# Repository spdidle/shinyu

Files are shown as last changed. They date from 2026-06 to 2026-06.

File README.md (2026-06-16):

# A-Side 🎼



## What is this?

A-Side is a cassette tape inspired hub to connect full size SD cards among other things to my laptop. I own several cameras but it's not convenient at all to find my dongle and connect it. So why not use a cute form to easily see your pictures!

## Why did I make this?

I love cassette tapes and cameras. That's it!

Loving cameras mean that every time I need to view my photos, upload my photos, anything to do with my photos, it's such a hassle! Grabbing my SD card reader, then my hard drive, sometimes another dongle... Anyways, it's just way too much work. So I decided to make my own SD card dongle-esque thing, with 2 USB-A ports to facilitate any connecting of hard drives, and 2 SD card slots to maximize the photo goodness. When I don't need to fiddle with photos, it can also act as a normal USB hub, allowing me to plug in keyboard or mice into my laptop.

## Features

- **2 USB-A ports** for portable hard drives, keyboards, or mice
- **2 Full-Size SD Card slots** for photos!
- **USB-C port** because nowadays, everything seems to be USB-C...

## How does it work?

Very self explanitory! Grab your favourite USB-C to USB-C cable, plug one end into your computer, the other into the hub, and voila! You are now able to plug whatever you want into this cute little cassette tape.

## Design

Designed in KiCad, schematic and board files are in this repo:
<p align="center">
  
  
  


</p>

Case was designed (+ rendered) in Fusion360:
<p align="center">

</p>

## BOM (Bill Of Materials)
|Designator |Component Name / Description  |Package |Value / Spec |Qty|Unit Price (USD)|Total (USD)|Primary Supplier|Part Number / Source Link |
|---|---|---|---|---|---|---|---|---|
|C1, C2 |Multilayer Ceramic Capacitor  |0805 |22pF |2  |0.4600 |$0.92 |LCSC |https://www.lcsc.com/product-detail/C1804.html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 |
|C3 |Multilayer Ceramic Capacitor  |0805 |1uF |1  |0.9400 |$0.94 |LCSC |https://www.lcsc.com/product-detail/C28323.html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 |
|C10 |Multilayer Ceramic Capacitor  |0805 |4.7uF |1  |0.4300 |$0.43 |LCSC |https://www.lcsc.com/product-detail/C1779.html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 |
|C11,C12,C13,C14,C15,C16,C17,C19,C20,C4,C5,C6,C7,C8,C9|Multilayer Ceramic Capacitor  |0805 |100nF |15 |0.0687 |$1.03 |LCSC |https://www.lcsc.com/product-detail/C49678.html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 |
|R1, R2, R5, R6 |Thick Film Chip Resistor |0805 |100 kΩ |4  |0.0825 |$0.33 |LCSC |https://www.lcsc.com/product-detail/C149504.html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 |
|R4 |Thick Film Chip Resistor |0805 |680 Ω |1  |0.2200 |$0.22 |LCSC |https://www.lcsc.com/product-detail/C17798.html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 |
|R7, R8 |Thick Film Chip Resistor |0805 |330 Ω |2  |0.1400 |$0.28 |LCSC |https://www.lcsc.com/product-detail/C17630.html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 |
|R10, R23 |Thick Film Chip Resistor |0805 |5.1 kΩ |2  |0.1400 |$0.28 |LCSC |https://www.lcsc.com/product-detail/C27834.html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 |
|R11-R20 |Thick Film Chip Resistor |0805 |10 kΩ |14 |0.0250 |$0.35 |LCSC |https://www.lcsc.com/product-detail/C17414.html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 |
|D1, D2 |Surface Mount Indicator LED |0805 |Standard Red/Green |2  |0.3350 |$0.67 |LCSC |https://www.lcsc.com/product-detail/C84256.html?s_z=s_p_NCD0805R1 |
|SW1 |SMT Tactile Push Button |3.9x2.9mm |1.6N / 2.0mm Height |1  |2.2100 |$2.21 |LCSC |https://www.lcsc.com/product-detail/C495942.html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|
|CARD1, CARD2 |Hinged MicroSD Card Slot |SMT |SD-106M Hinged |2  |0.5200 |$1.04 |LCSC |https://www.lcsc.com/product-detail/C266603.html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 |
|GL850G |USB 2.0 Hub Controller IC |SSOP-28 |GL850G-HHY22 |1  |0.5500 |$0.55 |LCSC |https://www.lcsc.com/product-detail/C136617.html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 |
|IC3, IC4 |USB SD Card Reader Controller |SOP-16 |GL823K-HCY04 |2  |0.4550 |$0.91 |LCSC |https://www.lcsc.com/product-detail/C284879.html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 |
|U1, U2 |TVS Diode ESD Protection Array|SOT-23-6 |SRV05-4 (Low Cap) |2  |0.2550 |$0.51 |LCSC |https://www.lcsc.com/product-detail/C2836319.html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 |
|USB1, USB2 |USB Type-A Receptacle |Through-Hole|Right Angle / 90° Female|2  |0.2450 |$0.49 |LCSC |https://www.lcsc.com/product-detail/C456018.html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|
|USB3 |USB Type-C Receptacle |SMT+TH |16-Pin 2MD Type-C |1  |1.4100 |$1.41 |LCSC |https://www.lcsc.com/product-detail/C2765186.html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 |
|Y2 |Quartz Resonator Crystal |3225 SMT |26.2982 MHz / 4-Pad |1  |0.1400 |$0.14 |LCSC |https://www.lcsc.com/product-detail/C2981681.html?s_z=n_q_3225-26.2982-22-10-10%252FA |
|PCB |Custom 2-Layer Circuit Board  |100x80mm |FR-4 / 1.6mm Thickness  |5  |0.7000 |$3.50 |JLCPCB |https://www.jlcpcb.com |
| | | | | | | | | |
| | | | | | |$16.21 | | |

## Build & Assembly
(I may or may not be larping, I've never soldered anything this miniscule before so bare with me and my limited theory knowledge)

### Required Tools
- Soldering iron
- Solder
- Tweezers
- Tacky Flux
- IPA & ESD Brush

### Assmebly  Steps

#### Solder on the microchips (the lowest profile ones), which include the GL850G, GL823K, and the ESD Protection Diodes.
1. Apply a thin layer of tacky flux to the PCB pads
2. Align and place the chip
3. Tack down one corner pin with a tiny dab of solder
4. Apply flux across all pins, and solder everything together

#### Solder on any passives, including resistors, caps, crystals, and LEDs
1. Use the two-pad SMT technique, applying a small dab of solder on one pad
2. Slide the component into the solder using tweezers
3. Solder the remaining pad

#### Solder on the electromechanical components, which include the tactile switch and SD card slots
1. Just do it? Haha?

#### Solder on the final, highest profile components, including the USB IO connectors
1. Put the connector into the holes on the PCB, and solder from the bottom
2. Use a magnifying glass for the USB-C, the 16 pins are going to be hell.

#### If you can afford PCBA, good for you. Ignore everything I just said >:(

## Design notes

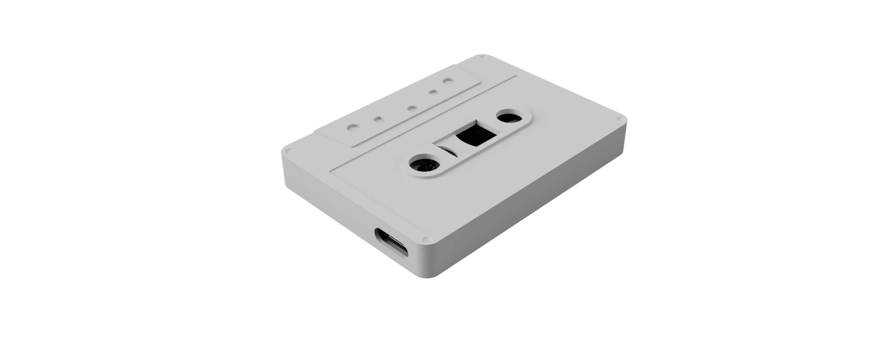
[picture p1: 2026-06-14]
images/render_ver2.png

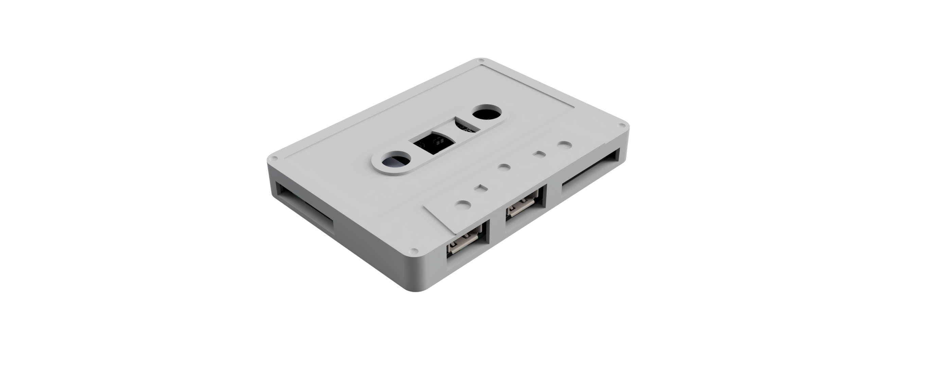
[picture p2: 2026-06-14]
images/render_ver1.png

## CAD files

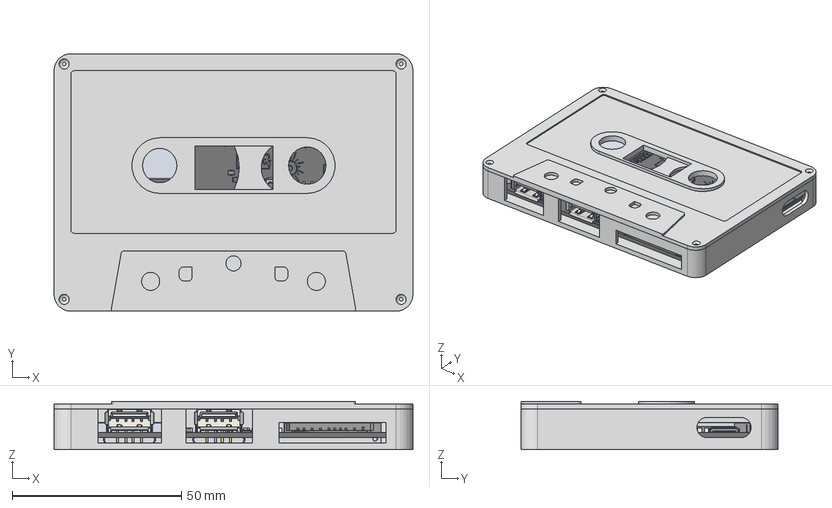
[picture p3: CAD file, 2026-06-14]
case/asideCase.step
106.0 x 76.0 x 14.2 mm

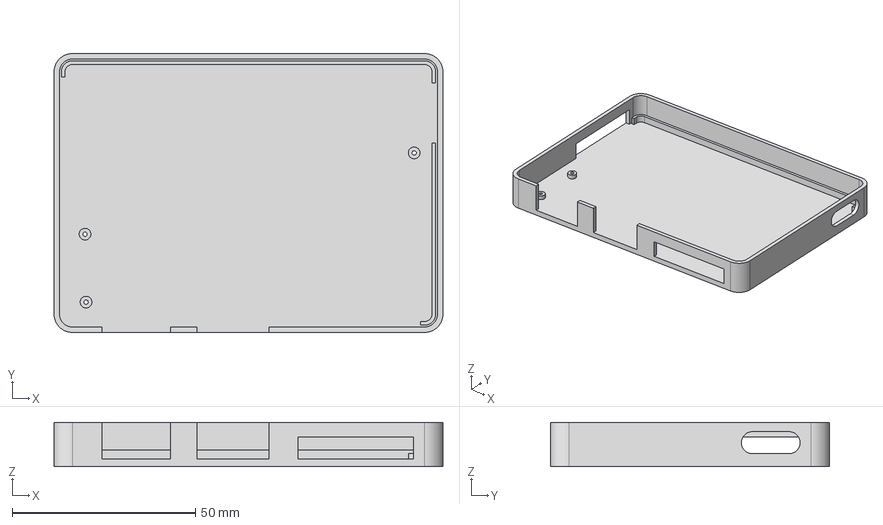
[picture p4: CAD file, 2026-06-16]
case/step files/caseBottom.step
106.0 x 76.0 x 12.0 mm

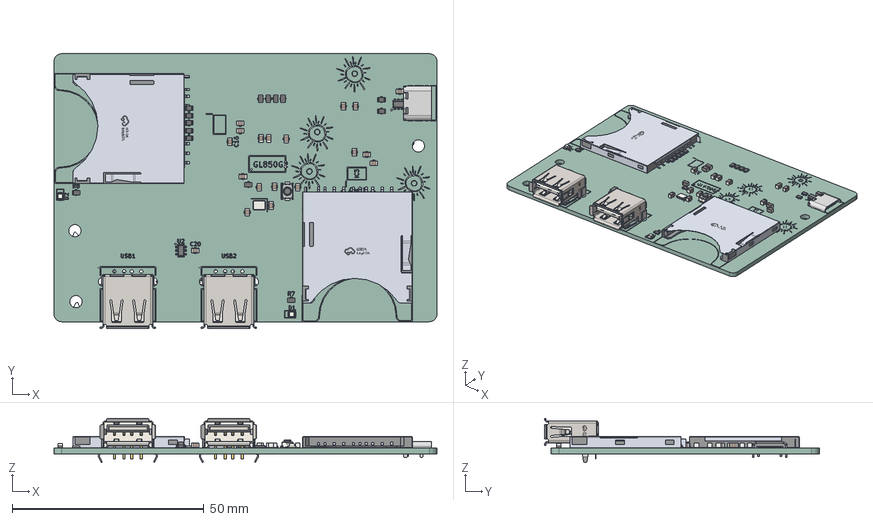
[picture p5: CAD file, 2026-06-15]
hardware/PCB/pcb.step
100.0 x 71.7 x 11.5 mm
R_0805_2012Metric x 19
C_0805_2012Metric x 19
USB-C-SMD_TYPE-C-6PIN-2MD-073
LED_0805_2012Metric x 2
SD-SMD_SD-106M x 2
SW_Push_SPST_NO_Alps_SKRK
SOT-23-6 x 2
USB-A-TH_4P-L14.5-W14.0-H7.6-S2.71 x 2
Crystal_SMD_3225-4Pin_3.2x2.5mm
a-side_silkscreen x 2
a-side_PCB

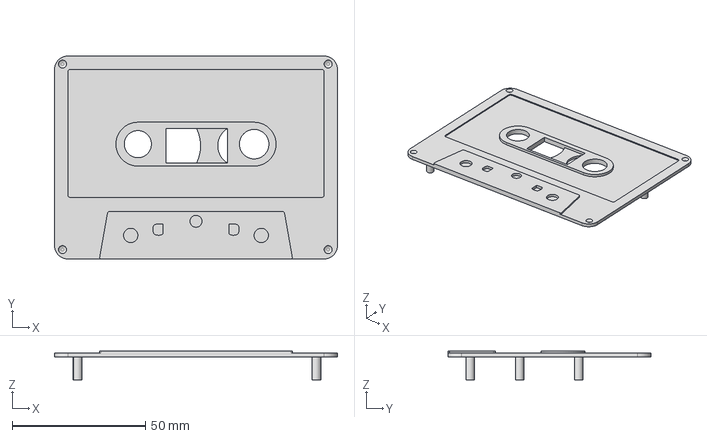
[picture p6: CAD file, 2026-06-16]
case/step files/caseTop.step
106.0 x 76.0 x 10.7 mm

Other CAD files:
case/f3d files/caseBottom.f3d
case/f3d files/caseTop.f3d

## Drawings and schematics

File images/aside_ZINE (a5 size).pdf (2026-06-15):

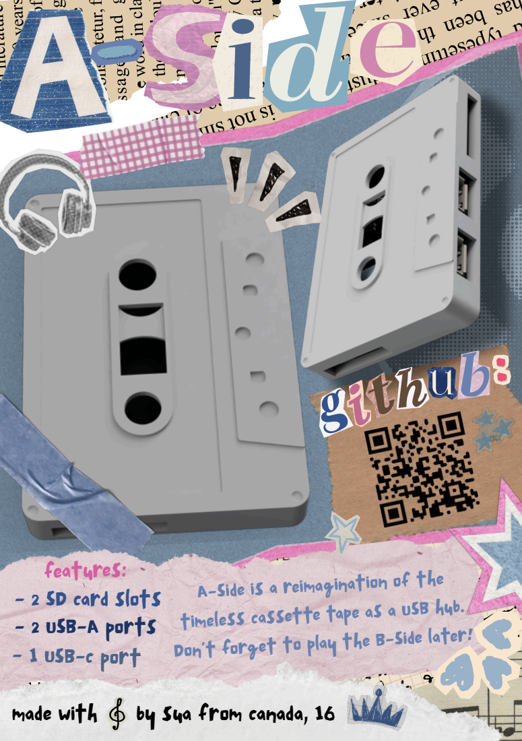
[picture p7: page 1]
Don

features:
- 2 SD card slots
- 2 USB-A ports

A-Side is a reimagination of the

timeless cassette tape as a USB hub.

’t forget to play the B-Side later!

- 1 USB-c port
made with by sua from canada, 16

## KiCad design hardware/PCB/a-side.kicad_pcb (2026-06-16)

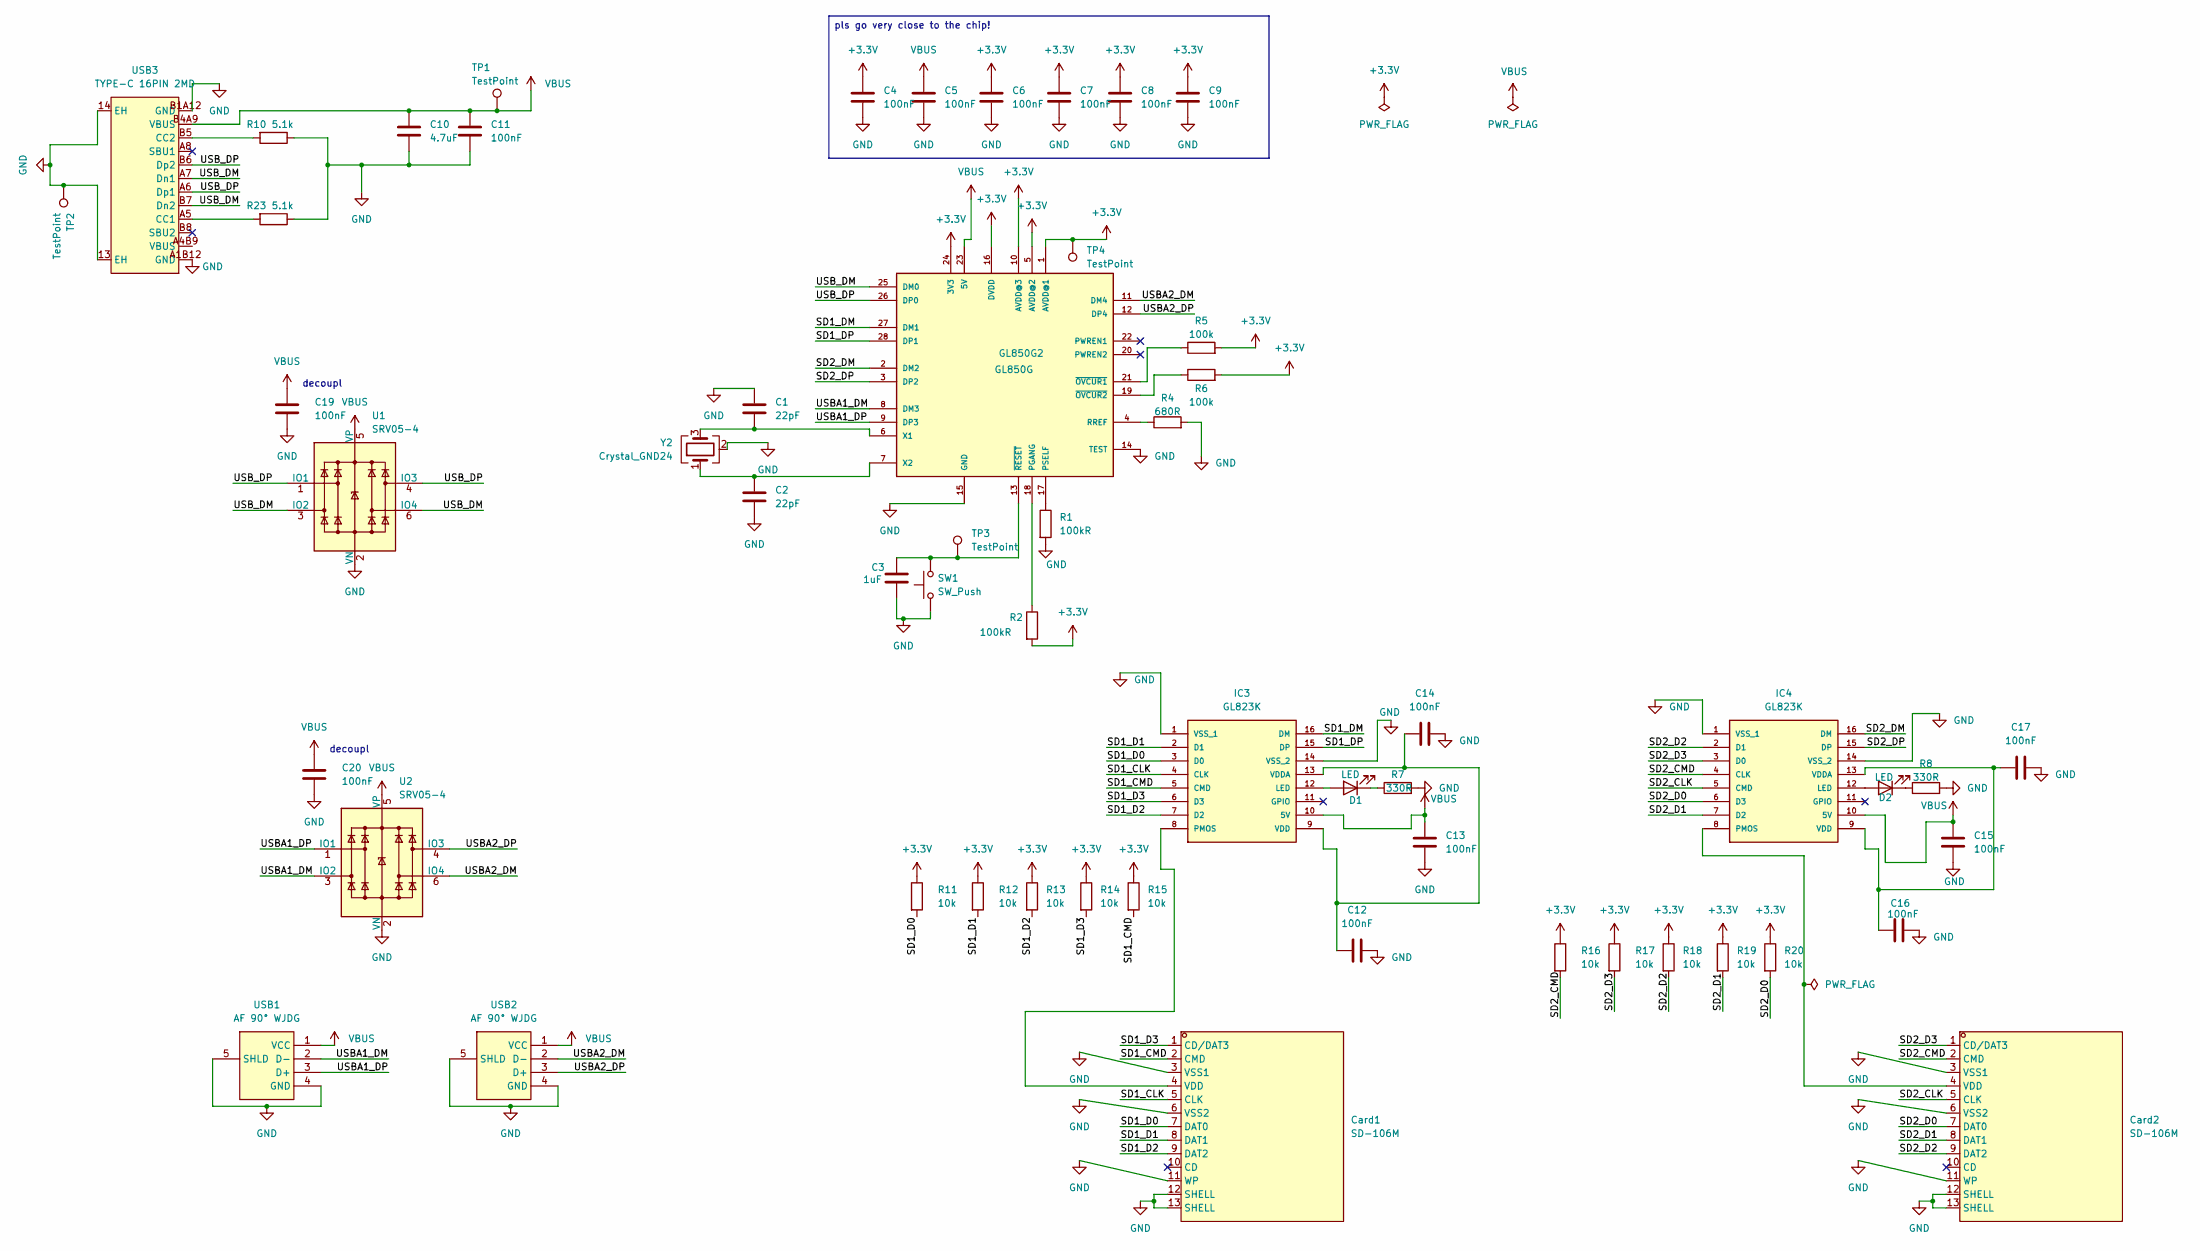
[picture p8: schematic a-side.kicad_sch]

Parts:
C1, C2: 22pF; C_0805_2012Metric
C3: 1uF; C_0805_2012Metric
C4, C5, C6, C7, C8, C9, C11, C12, C13, C14, C15, C16, C17, C19, C20: 100nF; C_0805_2012Metric
C10: 4.7uF; C_0805_2012Metric
Card1, Card2: SD-106M; SD-SMD_SD-106M; MPN SD-106M; LCSC Part C266603
D1, D2: LED; LED_0805_2012Metric_Pad1.15x1.40mm_HandSolder
GL850G2: GL850G; 28SSOP
IC3, IC4: GL823K; SOP64P600X175-16N; MANUFACTURER_PART_NUMBER GL823K
R1, R2: 100kR; R_0805_2012Metric
R4: 680R; R_0805_2012Metric
R5, R6: 100k; R_0805_2012Metric
R7, R8: 330R; R_0805_2012Metric
R10, R23: 5.1k; R_0805_2012Metric
R11, R12, R13, R14, R15, R16, R17, R18, R19, R20: 10k; R_0805_2012Metric
SW1: SW_Push; SW_Push_SPST_NO_Alps_SKRK
TP1, TP2, TP3, TP4: TestPoint; TestPoint_Pad_D1.0mm
U1, U2: SRV05-4; SOT-23-6
USB1, USB2: AF 90° WJDG; USB-A-TH_AF-WJDG; MPN AF 90° WJDG; LCSC Part C456018
USB3: TYPE-C 16PIN 2MD; USB-C-SMD_TYPE-C-16PIN-2MD-073; MPN TYPE-C 16PIN 2MD(073); LCSC Part C2765186
Y2: Crystal_GND24; Crystal_SMD_3225-4Pin_3.2x2.5mm

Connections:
+3.3V: C4.1, C6.1, C7.1, C8.1, C9.1, GL850G2.1 (AVDD@1), GL850G2.5 (AVDD@2), GL850G2.10 (AVDD@3), GL850G2.16 (DVDD), GL850G2.24 (3V3), R2.2, R5.2, R6.2, R11.1, R12.1, R13.1, R14.1, R15.1, R16.1, R17.1, R18.1, R19.1, R20.1, TP4.1 (1_1)
/SD1_CLK: Card1.5 (CLK), IC3.4 (CLK)
/SD1_CMD: Card1.2 (CMD), IC3.5 (CMD), R15.2
/SD1_D0: Card1.7 (DAT0), IC3.3 (D0), R11.2
/SD1_D1: Card1.8 (DAT1), IC3.2 (D1), R12.2
/SD1_D2: Card1.9 (DAT2), IC3.7 (D2), R13.2
/SD1_D3: Card1.1 (CD/DAT3), IC3.6 (D3), R14.2
/SD1_DM: GL850G2.27 (DM1), IC3.16 (DM)
/SD1_DP: GL850G2.28 (DP1), IC3.15 (DP)
/SD2_CLK: Card2.5 (CLK), IC4.5 (CMD)
/SD2_CMD: Card2.2 (CMD), IC4.4 (CLK), R16.2
/SD2_D0: Card2.7 (DAT0), IC4.6 (D3), R20.2
/SD2_D1: Card2.8 (DAT1), IC4.7 (D2), R19.2
/SD2_D2: Card2.9 (DAT2), IC4.2 (D1), R18.2
/SD2_D3: Card2.1 (CD/DAT3), IC4.3 (D0), R17.2
/SD2_DM: GL850G2.2 (DM2), IC4.16 (DM)
/SD2_DP: GL850G2.3 (DP2), IC4.15 (DP)
/USBA1_DM: GL850G2.8 (DM3), U2.3 (IO2), USB1.2 (D-)
/USBA1_DP: GL850G2.9 (DP3), U2.1 (IO1), USB1.3 (D+)
/USBA2_DM: GL850G2.11 (DM4), U2.6 (IO4), USB2.2 (D-)
/USBA2_DP: GL850G2.12 (DP4), U2.4 (IO3), USB2.3 (D+)
/USB_DM: GL850G2.25 (DM0), U1.3 (IO2), U1.6 (IO4), USB3.A7 (Dn1), USB3.B7 (Dn2)
/USB_DP: GL850G2.26 (DP0), U1.1 (IO1), U1.4 (IO3), USB3.A6 (Dp1), USB3.B6 (Dp2)
GND: C1.1, C2.2, C3.1, C4.2, C5.2, C6.2, C7.2, C8.2, C9.2, C10.1, C11.2, C12.2, C13.2, C14.2, C15.2, C16.2, C17.2, C19.2, C20.2, Card1.3 (VSS1), Card1.6 (VSS2), Card1.11 (WP), Card1.12 (SHELL), Card1.13 (SHELL), Card2.3 (VSS1), Card2.6 (VSS2), Card2.11 (WP), Card2.12 (SHELL), Card2.13 (SHELL), GL850G2.14 (TEST), GL850G2.15 (GND), IC3.1 (VSS_1), IC3.14 (VSS_2), IC4.1 (VSS_1), IC4.14 (VSS_2), R1.2, R4.2, R7.2, R8.2, R10.1, R23.1, SW1.1, TP2.1 (1_1), U1.2 (VN), U2.2 (VN), USB1.4 (GND), USB1.5 (SHLD), USB2.4 (GND), USB2.5 (SHLD), USB3.13 (EH), USB3.14 (EH), USB3.A1B12 (GND), USB3.B1A12 (GND), Y2.2 (G), Y2.4 (G)
unnamed: Card1.4 (VDD), IC3.8 (PMOS)
unnamed: Card2.4 (VDD), IC4.8 (PMOS)
unnamed: D1.2 (A), IC3.12 (LED)
unnamed: D1.1 (K), R7.1
unnamed: D2.2 (A), IC4.12 (LED)
unnamed: D2.1 (K), R8.1
unnamed: GL850G2.18 (PGANG), R2.1
unnamed: GL850G2.17 (PSELF), R1.1
unnamed: GL850G2.4 (RREF), R4.1
unnamed: C1.2, GL850G2.6 (X1), Y2.3
unnamed: C2.1, GL850G2.7 (X2), Y2.1
unnamed: GL850G2.21 (~OVCUR1), R5.1
unnamed: GL850G2.19 (~OVCUR2), R6.1
unnamed: C3.2, GL850G2.13 (~RESET), SW1.2, TP3.1 (1_1)
unnamed: C12.1, C14.1, IC3.9 (VDD), IC3.13 (VDDA)
unnamed: C16.1, C17.1, IC4.9 (VDD), IC4.13 (VDDA)
unnamed: R23.2, USB3.A5 (CC1)
unnamed: R10.2, USB3.B5 (CC2)
VBUS: C5.1, C10.2, C11.1, C13.1, C15.1, C19.1, C20.1, GL850G2.23 (5V), IC3.10 (5V), IC4.10 (5V), TP1.1 (1_1), U1.5 (VP), U2.5 (VP), USB1.1 (VCC), USB2.1 (VCC), USB3.B4A9 (VBUS)

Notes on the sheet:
decoupl
pls go very close to the chip!

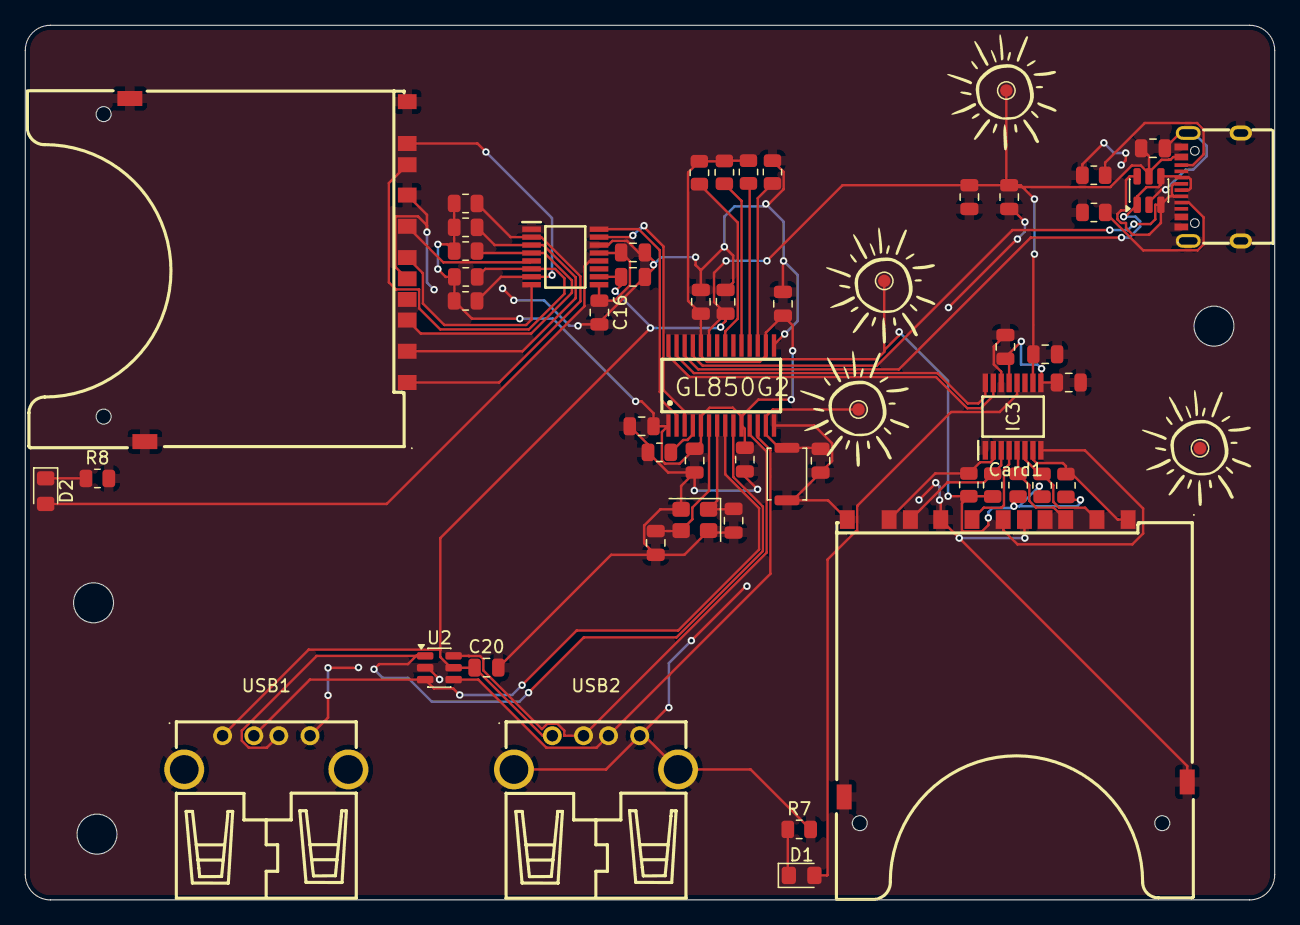
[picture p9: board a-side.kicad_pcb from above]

Board: 2 copper layers, 100.0 x 70.0 mm, 56 parts (0 on the bottom side), 43 nets.

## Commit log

2026-04-06 last com 4 tonight
    kicking ts bucket. finished tracing with 0 errors and opened my 3d viewer to see i had the wrong footprint for my usb c plug 🥰 that no its actuallyt amazing! its exactly what i wanted! so im restarting TOMORROW aint NO WAY im doing this tonight
    [shinyu.kicad_sch]
2026-04-12 okay. i give up.
    fine lapse you win. i lost all a nights work! you are the besttt! thank you! also changed the name because i crashed out so hard today that i changed the entire direction of the project. fun times.
    [a-side.kicad_pcb, a-side.kicad_sch, shinyu.kicad_pcb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]
2026-04-13 ???? short ahh
    cant sleep so decided to do a 5 min work sesh , added 2 leds for the sd card readers ohh my god chat i literally cant fall asleep its 4 am 😭
    [a-side.kicad_pcb, a-side.kicad_sch]
2026-04-15 last commie of the day!
    fixed major issues earlier, rn just fixing some decoupling caps here and there heh i mean all in a days work what can i say
    [a-side.kicad_pcb, a-side.kicad_sch]
2026-04-18 fixing..
    schematic... fixing orientation on stuffs... fixing footprints again... fixing...
    [a-side.kicad_pcb, a-side.kicad_sch]
2026-06-14 getting deep into routing
    just gonna commit rn coz im a little locked in but uhh yea schema done i think, footprints all found
    [a-side.kicad_sch]
2026-06-14 DOME
    done done done DONE 0 errors 108982 warnings who gaf im done
    [a-side.kicad_pcb, a-side.kicad_sch]
2026-06-14 im actually moronic
    how did i forget mounting holes. and also. THEY DONT FIT IN THE 4 CORNERS should i just die
    [a-side.kicad_pcb]
2026-06-14 import, export blahhh
    get the case done and exporting some final stuff iwth pcb and case
    [a-side-B_Cu.gbr, a-side-B_Mask.gbr, a-side-B_Paste.gbr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]
2026-06-15 stupid pcb still says g
    made a mistaje on silkscreen, redid the exporrts and pcb.step file
    [a-side-B_Cu.gbr, a-side-B_Mask.gbr, a-side-B_Paste.gbr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]
2026-06-15 blahhhh readmetime
    [a-side.kicad_pcb]
2026-06-16 update readme
    update readme with new assembly/solder instructions and bom
2026-06-16 polish
    + gitignore
    + reorganize files
    + add bom to hardware folder
    + delete unnecessary clutter
    [a-side-B_Cu.gbr, a-side-B_Mask.gbr, a-side-B_Paste.gbr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]
2026-06-16 added step files
    i dont thnnk i need this but just in CASE HAHAHAHAHAHA GET IT JUST IN CASE AS IN THE 3D CASE
    [caseBottom.f3d, caseBottom.step, caseTop.f3d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]
